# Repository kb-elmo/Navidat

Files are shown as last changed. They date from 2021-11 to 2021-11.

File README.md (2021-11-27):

# Navidat

[][cc-by-nc-sa]<a href="https://ko-fi.com/kb_elmo">kofibadge</a>

### Full navigation keypad

header

---

[STEP files for the case](case/)

[KiCAD PCB files](pcb/)

[Gerbers for PCB production](pcb/gerbers/)

[JLCPCB BOM](pcb/fab/navidat_bom_jlc.csv)

[JLCPCB CPL](pcb/fab/navidat_cpl_jlc.csv)

[Vial-QMK firmware](firmware/)

---

This work is licensed under a
[Creative Commons Attribution-NonCommercial-ShareAlike 4.0 International License][cc-by-nc-sa].

[][cc-by-nc-sa]

[cc-by-nc-sa]: http://creativecommons.org/licenses/by-nc-sa/4.0/
[cc-by-nc-sa-image]: https://licensebuttons.net/l/by-nc-sa/4.0/88x31.png
[cc-by-nc-sa-shield]: https://img.shields.io/badge/License-CC%20BY--NC--SA%204.0-lightgrey.svg

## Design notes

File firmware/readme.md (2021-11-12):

# Navidat

navidat

Full navigation keypad

* Keyboard Maintainer: [kb-elmo](https://github.com/kb-elmo)
* Hardware Supported: Navidat rev.1 PCB
* Hardware Availability: [Open source project](https://github.com/kb-elmo/Navidat)

Make example for this keyboard (after setting up your build environment):

    make kb_elmo/navidat:default

Flashing example for this keyboard:

    make kb_elmo/navidat:default:flash

See the [build environment setup](https://docs.qmk.fm/#/getting_started_build_tools) and the [make instructions](https://docs.qmk.fm/#/getting_started_make_guide) for more information. Brand new to QMK? Start with our [Complete Newbs Guide](https://docs.qmk.fm/#/newbs).

## Bootloader

* **Bootmagic reset**: Hold down the top left key and plug in the keyboard
* **Physical reset button**: Briefly press the button labeled "Reset" on the back of the PCB
* **Keycode in layout**: Press the key mapped to `RESET` if it is available

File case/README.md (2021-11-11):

# Navidat case

### These files are meant for 3D printing only! 

They are not suitable for CNC machining and trying to use them for that will most likely result in failure of the parts.

The top piece should be printed upside down with supports for the integrated plate to get the best looking results.  
The bottom can be printed without any supports in it's natural orientation.

The bottom part is a simple friction fit into the top.  
Make sure that everything works and is installed properly on the PCB when putting the case together.  
Removing the bottom piece later is not really easy.

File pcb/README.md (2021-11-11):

# Navidat PCB

### Features

- Powered by an Atmega32u2
- Basic ESD and overvoltage protection
- Centered USB type-C port for a detachable cable
- Fully programmable using [QMK](https://qmk.fm) and [Vial](https://get.vial.today)

---

### Preview

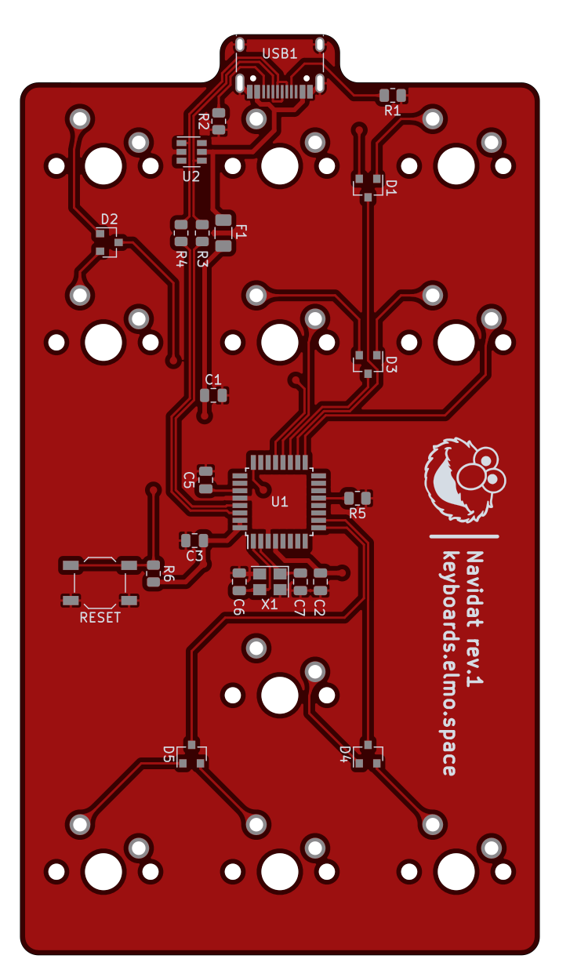
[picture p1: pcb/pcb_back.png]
pcb_back
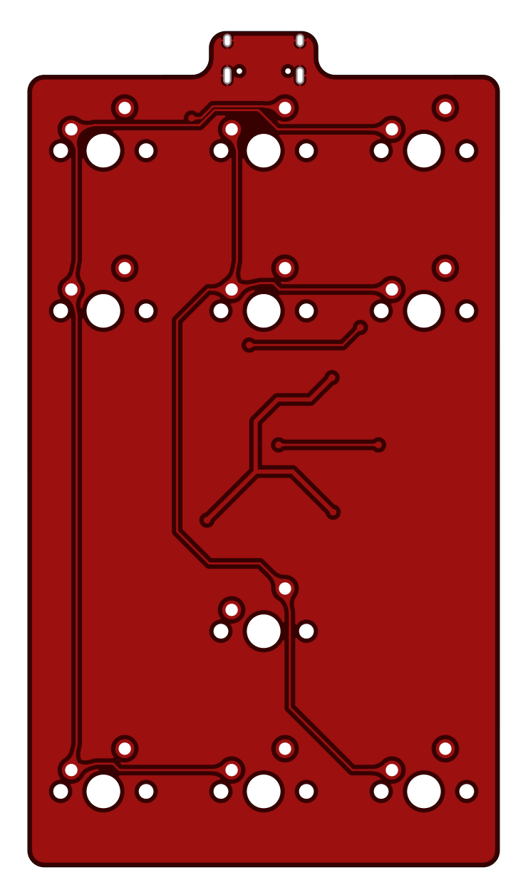
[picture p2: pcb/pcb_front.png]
pcb_front


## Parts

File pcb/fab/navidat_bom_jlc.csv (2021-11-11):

Comment | Designator | Footprint | LCSC Part #
10uF | C1 | C_0805_2012Metric | C91245
0.1uF | C2,C3 | C_0805_2012Metric | C49678
1uF | C5 | C_0805_2012Metric | C28323
22pF | C6,C7 | C_0805_2012Metric | C1804
D_AAK_Small | D1,D2,D3,D4,D5 | D_SOT-23_ANK_norm | C68978
Polyfuse_Small | F1 | Fuse_1206_3216Metric | C69688
5.1k | R1,R2 | R_0805_2012Metric | C27834
22 | R3,R4 | R_0805_2012Metric | C17561
10k | R5,R6 | R_0805_2012Metric | C17414
SW_Push | RESET1 | SW_SPST_TL3342 | C318884
ATmega32U2-AU | U1 | TQFP-32_7x7mm_P0.8mm | C618733
SRV05-4 | U2 | SOT-23-6 | C85364
USB_C_Receptacle_USB2.0 | USB1 | USB_C_Receptacle_HRO_TYPE-C-31-M-12 | C165948
Crystal_GND24_Small | X1 | Crystal_SMD_3225-4Pin_3.2x2.5mm | C13738

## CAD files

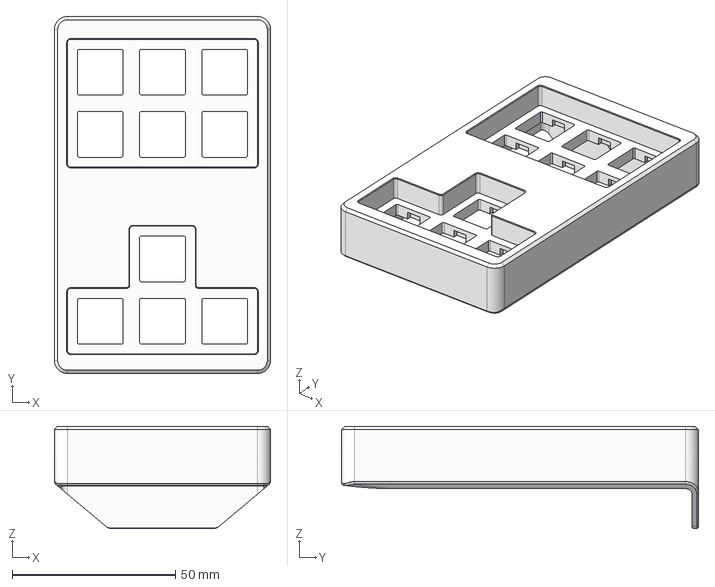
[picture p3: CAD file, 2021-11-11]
case/navidat_top.step
66.2 x 109.3 x 31.4 mm

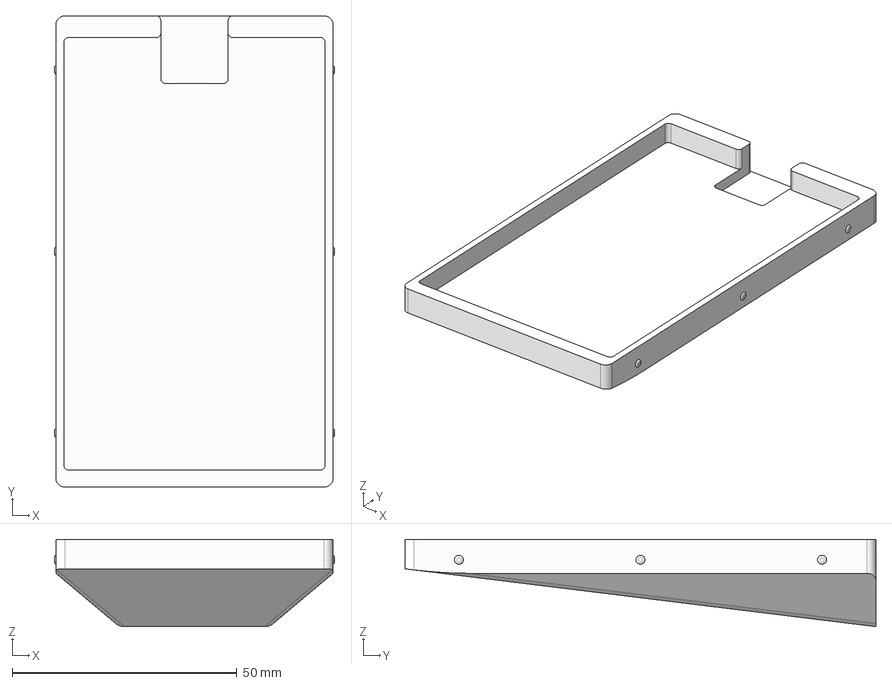
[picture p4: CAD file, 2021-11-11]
case/navidat_bottom.step
62.4 x 104.9 x 19.4 mm

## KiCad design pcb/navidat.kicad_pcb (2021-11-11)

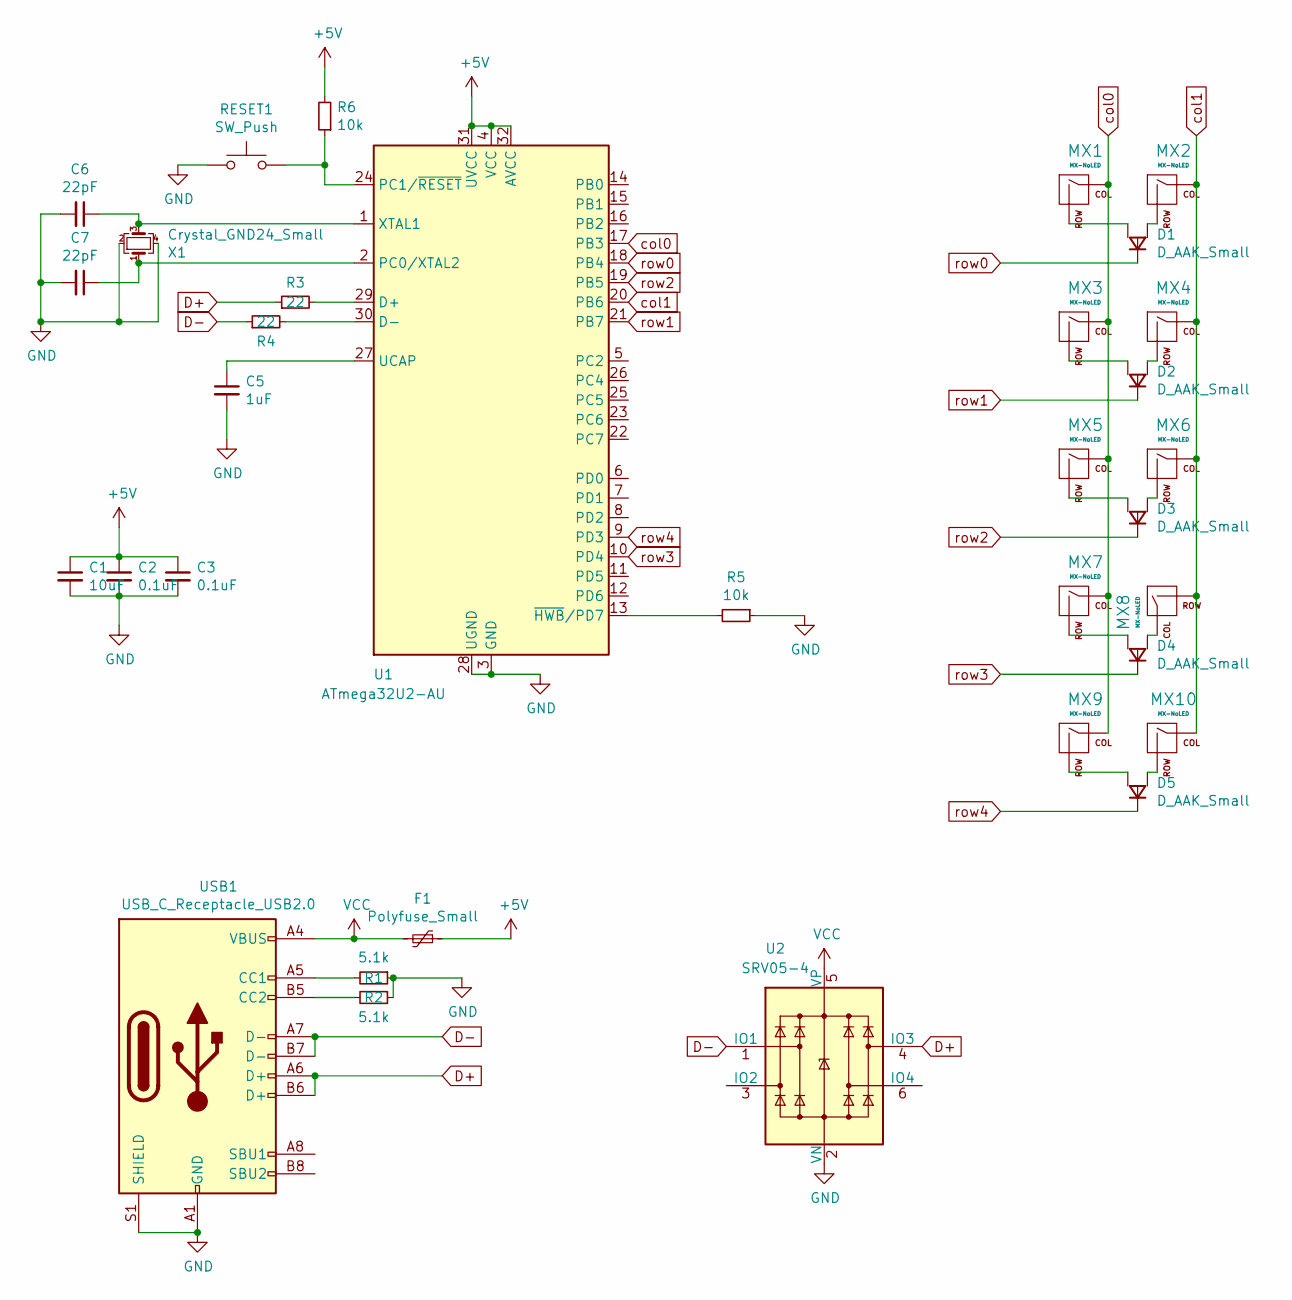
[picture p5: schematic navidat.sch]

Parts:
C1: 10uF; C_0805_2012Metric; LCSC C91245
C2, C3: 0.1uF; C_0805_2012Metric; LCSC C49678
C5: 1uF; C_0805_2012Metric; LCSC C28323
C6, C7: 22pF; C_0805_2012Metric; LCSC C1804
D1, D2, D3, D4, D5: D_AAK_Small; D_SOT-23_ANK_norm; LCSC C68978
F1: Polyfuse_Small; Fuse_1206_3216Metric; LCSC C69688
MX1, MX2, MX3, MX4, MX5, MX6, MX7, MX8, MX9, MX10: MX-NoLED; MXOnly-1U-NoLED
R1, R2: 5.1k; R_0805_2012Metric; LCSC C27834
R3, R4: 22; R_0805_2012Metric; LCSC C17561
R5, R6: 10k; R_0805_2012Metric; LCSC C17414
RESET1: SW_Push; SW_SPST_TL3342; LCSC C318884
U1: ATmega32U2-AU; TQFP-32_7x7mm_P0.8mm; LCSC C618733
U2: SRV05-4; SOT-23-6; LCSC C85364
USB1: USB_C_Receptacle_USB2.0; USB_C_Receptacle_HRO_TYPE-C-31-M-12; LCSC C165948
X1: Crystal_GND24_Small; Crystal_SMD_3225-4Pin_3.2x2.5mm; LCSC C13738

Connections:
+5V: C1.1, C2.1, C3.1, F1.1, R6.2, U1.4 (VCC), U1.31 (UVCC), U1.32 (AVCC)
D+: R3.1, U2.4 (IO3), USB1.A6 (D+), USB1.B6 (D+)
D-: R4.1, U2.1 (IO1), USB1.A7 (D-), USB1.B7 (D-)
GND: C1.2, C2.2, C3.2, C5.2, C6.2, C7.2, R1.1, R2.1, R5.1, RESET1.1, U1.3 (GND), U1.28 (UGND), U2.2 (VN), USB1.A1 (GND), USB1.A12 (GND), USB1.B1 (GND), USB1.B12 (GND), USB1.S1 (SHIELD), X1.2, X1.4; also elsewhere on the board
unnamed: C5.1, U1.27 (UCAP)
unnamed: C6.1, U1.1 (XTAL1), X1.3
unnamed: C7.1, U1.2 (PC0/XTAL2), X1.1
unnamed: D1.2 (A1), MX1.2 (ROW)
unnamed: D1.3 (A2), MX2.2 (ROW)
unnamed: D2.2 (A1), MX3.2 (ROW)
unnamed: D2.3 (A2), MX4.2 (ROW)
unnamed: D3.2 (A1), MX5.2 (ROW)
unnamed: D3.3 (A2), MX6.2 (ROW)
unnamed: D4.2 (A1), MX8.1 (COL)
unnamed: D4.3 (A2), MX7.2 (ROW)
unnamed: D5.2 (A1), MX10.2 (ROW)
unnamed: D5.3 (A2), MX9.2 (ROW)
unnamed: R1.2, USB1.A5 (CC1)
unnamed: R2.2, USB1.B5 (CC2)
unnamed: R3.2, U1.29 (D+)
unnamed: R4.2, U1.30 (D-)
unnamed: R5.2, U1.13 (~HWB~/PD7)
unnamed 22: R6.1, RESET1.2, U1.24 (PC1/~RESET); also elsewhere on the board
VCC: F1.2, U2.5 (VP), USB1.A4 (VBUS), USB1.A9 (VBUS), USB1.B4 (VBUS), USB1.B9 (VBUS)
col0: MX1.1 (COL), MX3.1 (COL), MX5.1 (COL), MX7.1 (COL), MX9.1 (COL), U1.17 (PB3)
col1: MX2.1 (COL), MX4.1 (COL), MX6.1 (COL), MX8.2 (ROW), MX10.1 (COL), U1.20 (PB6)
row0: D1.1 (K), U1.18 (PB4)
row1: D2.1 (K), U1.21 (PB7)
row2: D3.1 (K), U1.19 (PB5)
row3: D4.1 (K), U1.10 (PD4)
row4: D5.1 (K), U1.9 (PD3)

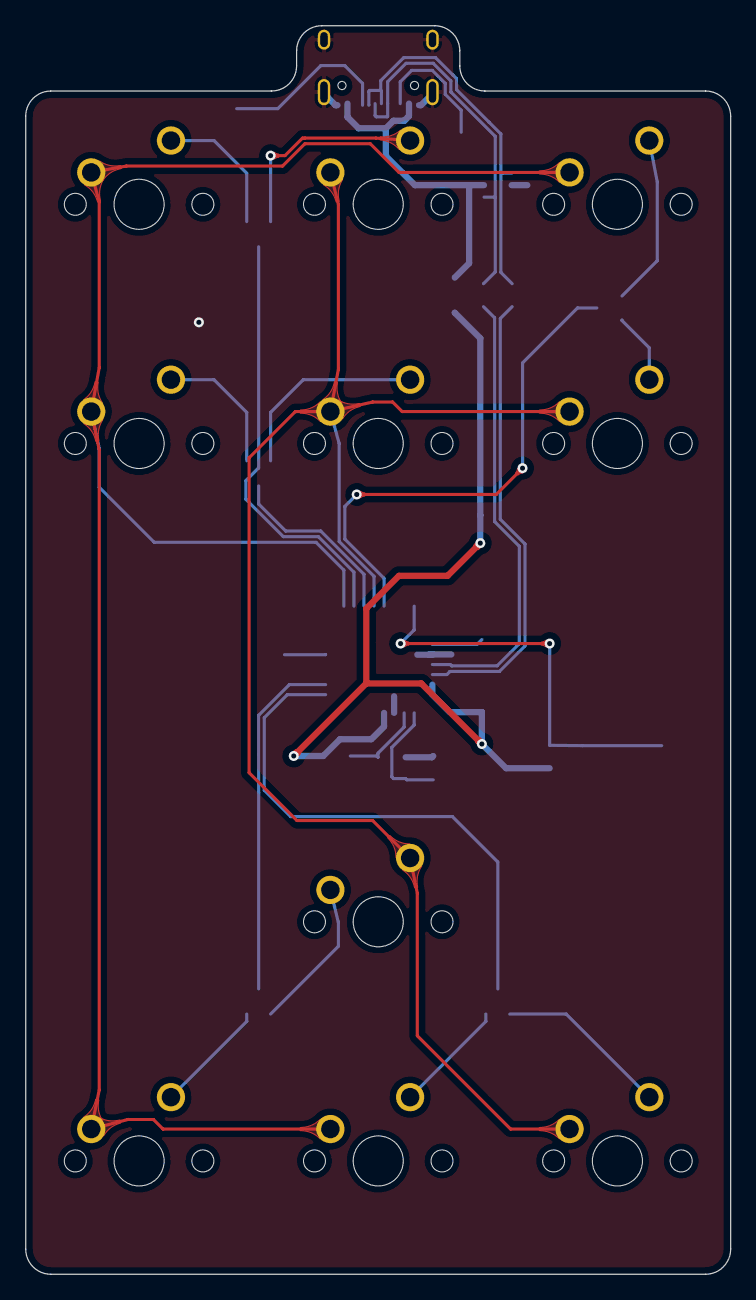
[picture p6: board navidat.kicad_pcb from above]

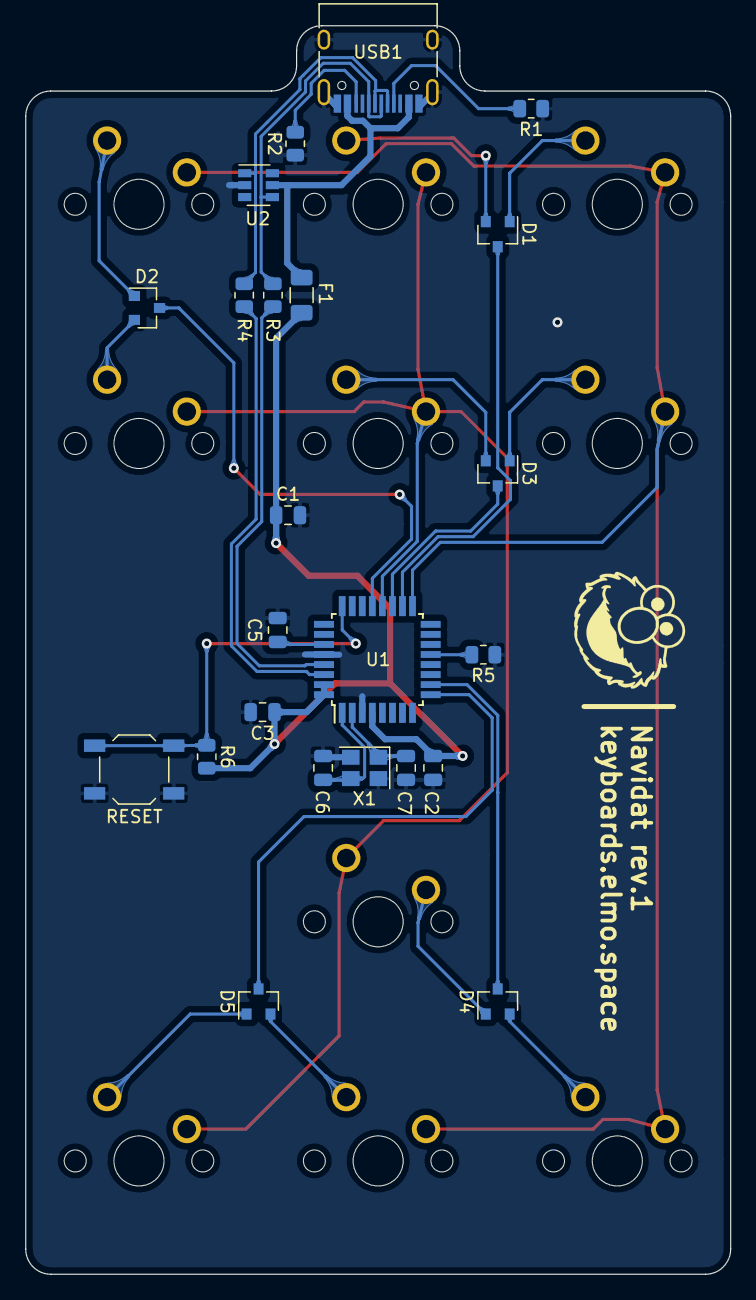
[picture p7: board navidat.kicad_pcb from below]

Board: 2 copper layers, 56.2 x 99.5 mm, 33 parts (23 on the bottom side), 31 nets.

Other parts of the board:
RESET: SW_Push; SW_SPST_TL3342

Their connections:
GND: RESET.1; also elsewhere on the board
unnamed 22: RESET.2; also elsewhere on the board

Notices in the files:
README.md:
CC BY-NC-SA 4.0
